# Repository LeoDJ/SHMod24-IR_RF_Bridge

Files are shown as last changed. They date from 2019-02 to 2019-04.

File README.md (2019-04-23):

# SHMod24 Addon: RF/IR Bridge

This addon is meant to be plugged onto a [SHMod24](https://github.com/LeoDJ/SHMod24) base board.
It provides the ability to send and receive infrared and 433MHz RF remote control codes.

**Current status**: a prototype PCB batch has been ordered and will be tested for functionality

## 3D Preview

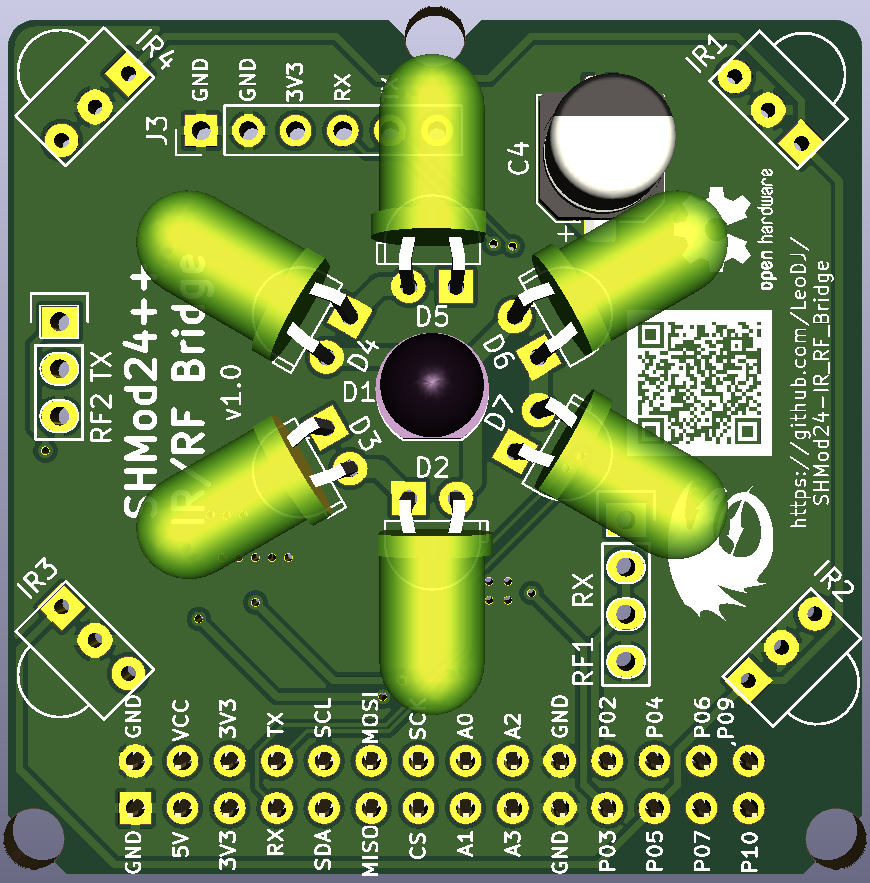
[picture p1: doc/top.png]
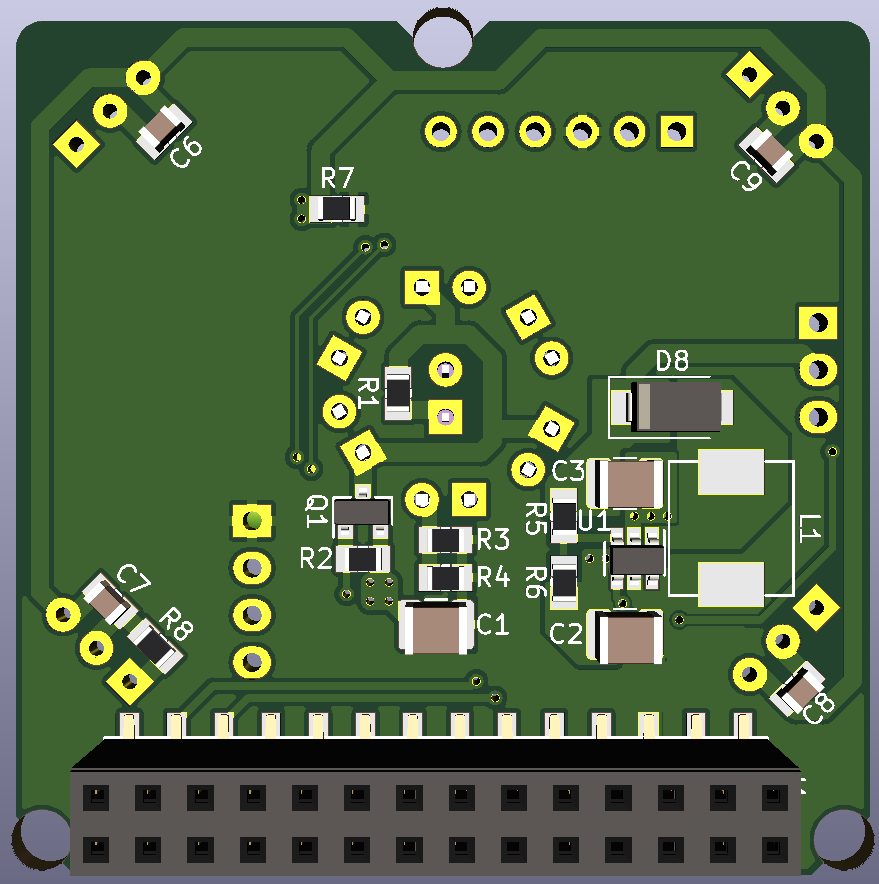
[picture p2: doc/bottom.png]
|  |  |
| :--- | :--- |
| []() | []() |

## BOM
There are multiple different module groups that can be populated.

 In the table is listed, which components to populate for a given module:

| Module | Reference | Part |
| :--- | :--- | :--- |
| **IR LED Array** | Q1 | AO3400A |
| | R1 | 15Ω |
| | R2 | 10k |
| | R3, R4 | 2Ω |
| | C1 | 22µF, 1210 |
| | D1 - D7 | IR LED 5mm |
| | | |
| **IR Receiver Array** | R7 | 100Ω |
| | C4 | 100µF, 6.3x5.8 |
| | R8 | 47k |
| | C6 - C9 | 100n |
| | IR1 - IR4 | VS1838b |
| | | |
| **433MHz 12V Boost Converter** | U1 | MT3608 |
| Can also be bypassed by | R5 | 180k |
| bridging L1 and D8 to run | R6 | 10k |
| 433MHz transmitter at 3.3V | D8 | SS34 Schottky, SMA |
| | C2, C3 | 22µF, 1210 |
| | L1 | 4.7µH, 0630 |
| | | |
| **433MHz Receiver** | RF1 | Generic China 433MHz RX |
| | | |
| **433MHz Transmitter** | RF2 | Generic China 433MHz TX |

## Project installation
- Make sure to run `git clone` with `--recurse-submodules` to include the necessary libraries too.

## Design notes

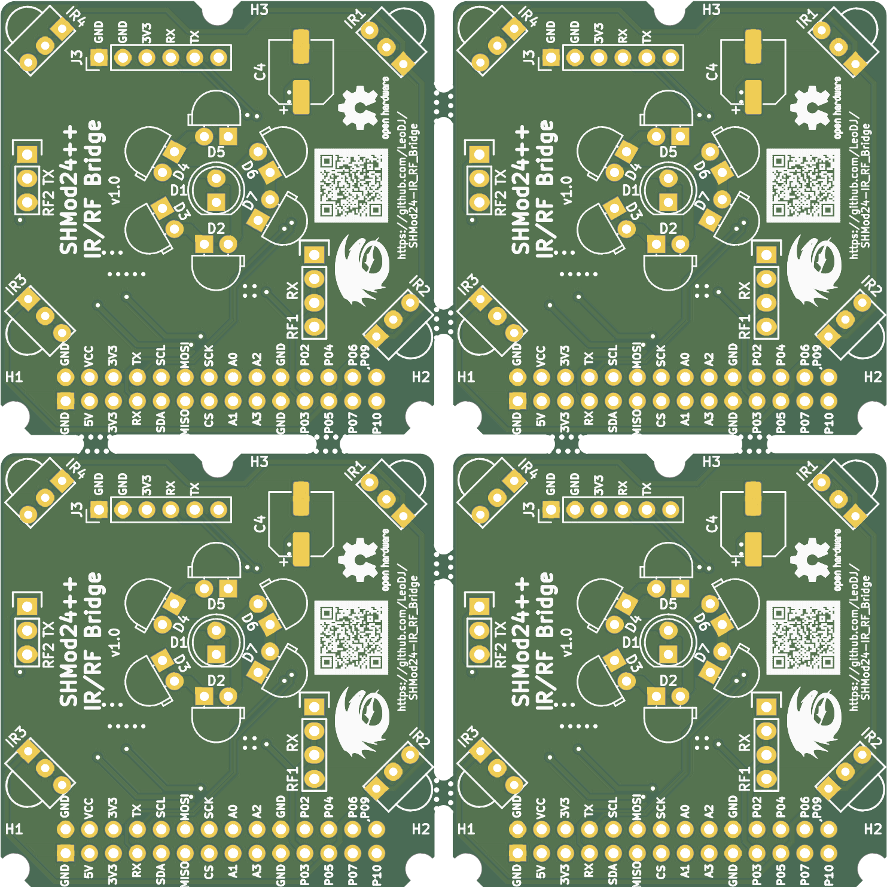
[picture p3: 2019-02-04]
gerber/panelized/panelized_Combined_Top.png

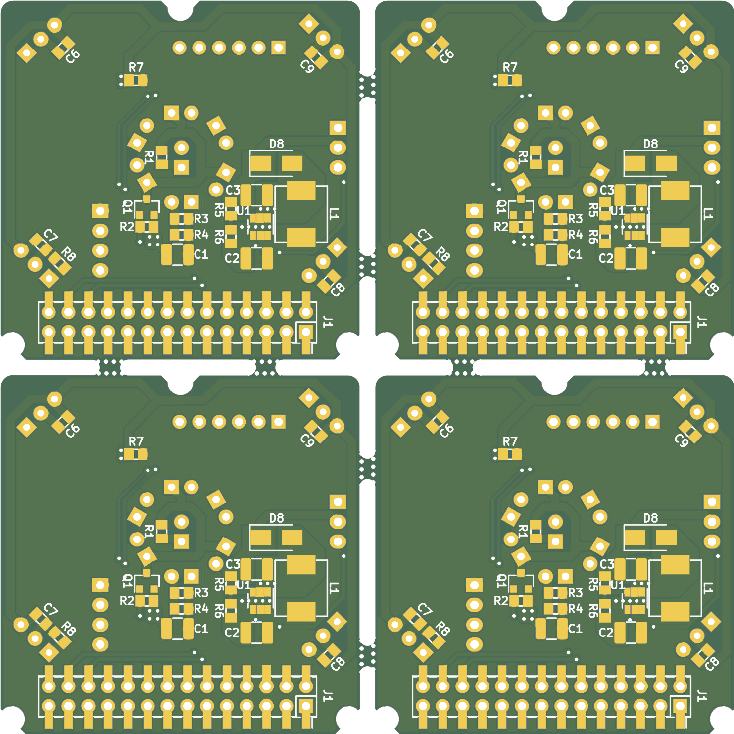
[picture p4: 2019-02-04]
gerber/panelized/panelized_Combined_Bottom.png

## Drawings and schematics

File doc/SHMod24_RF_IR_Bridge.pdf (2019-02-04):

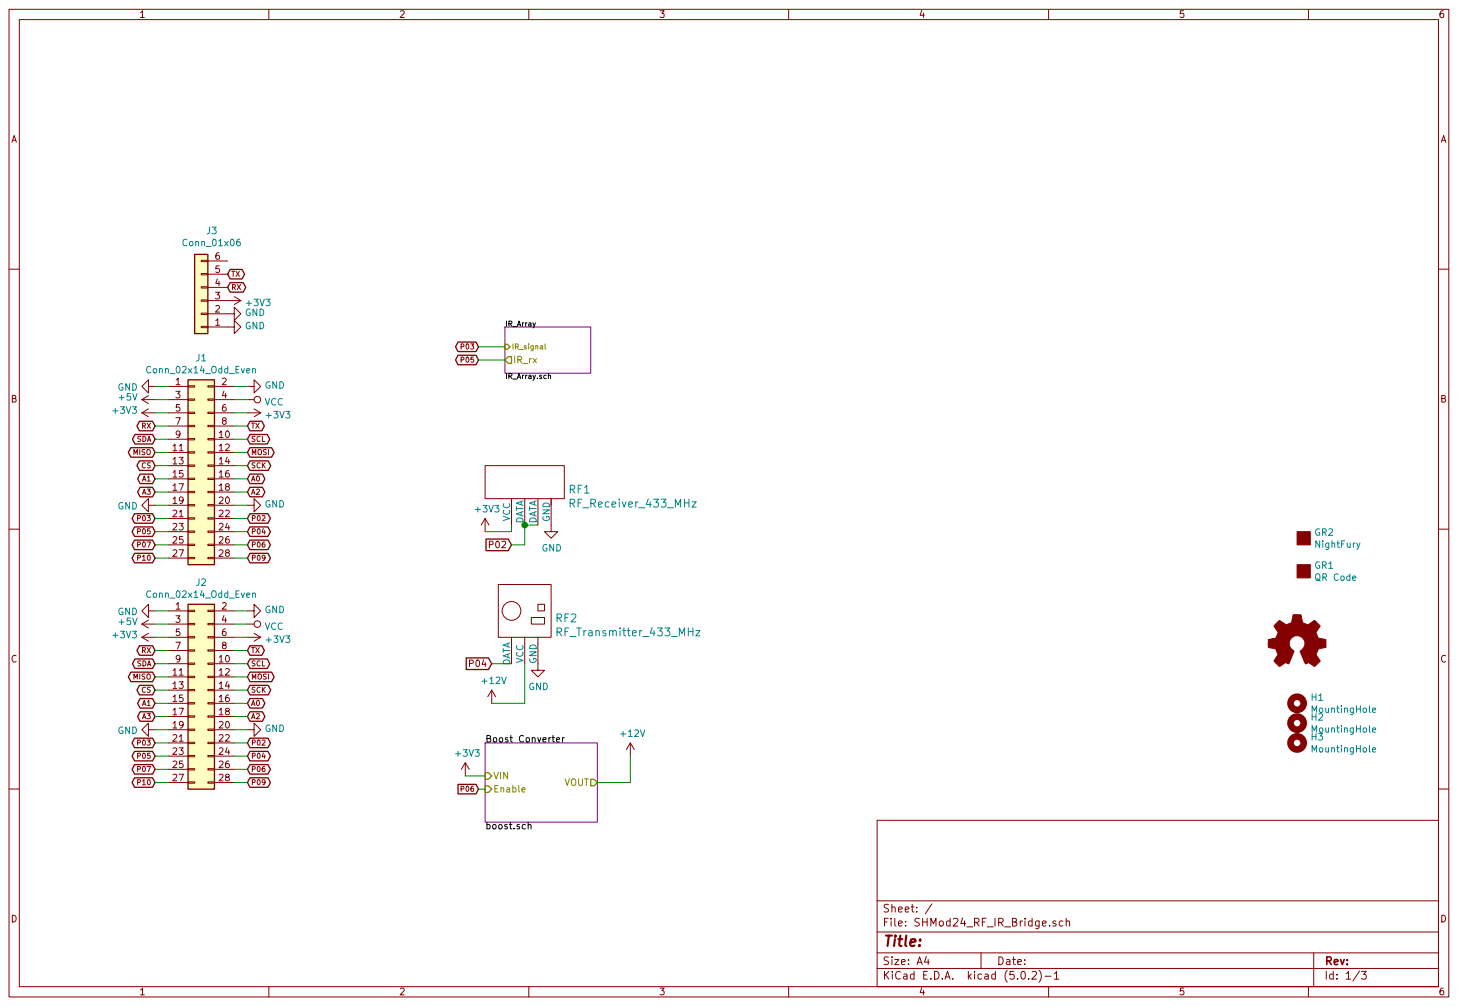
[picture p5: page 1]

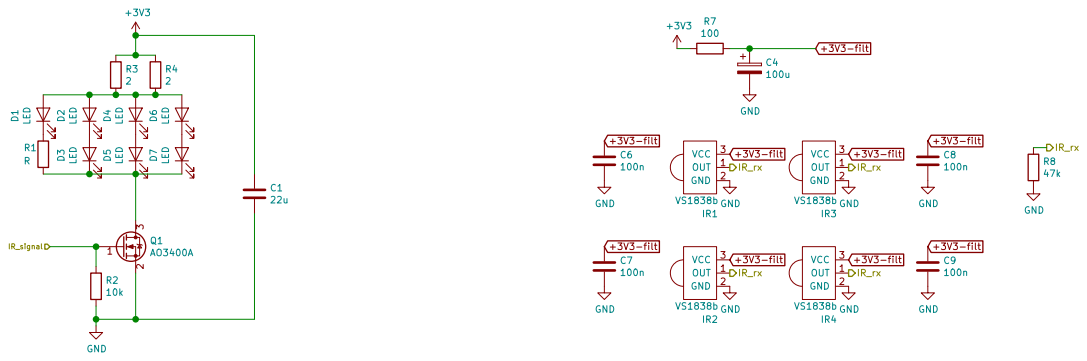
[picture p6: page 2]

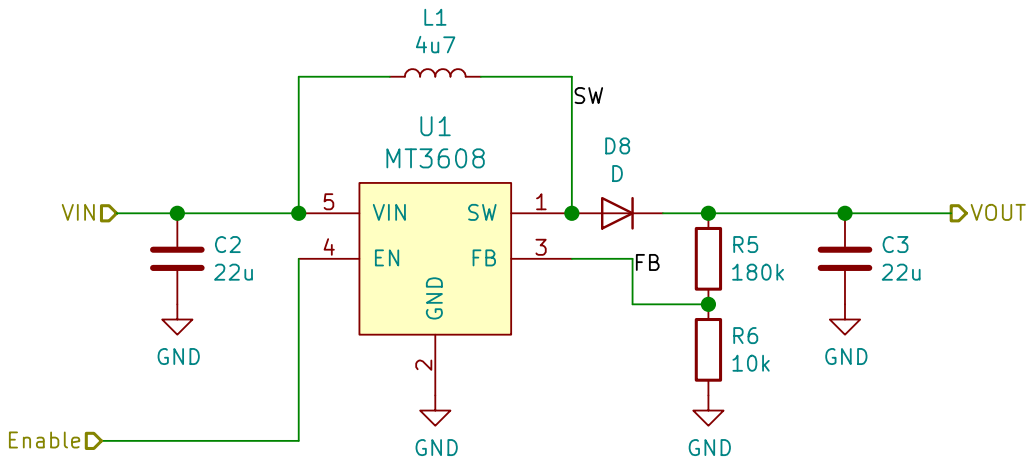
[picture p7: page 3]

2 FB 3 EN 4 VIN 5 U1 MT3608 GND

Id: 3/3 Title: File: boost.sch Sheet: /Boost Converter/

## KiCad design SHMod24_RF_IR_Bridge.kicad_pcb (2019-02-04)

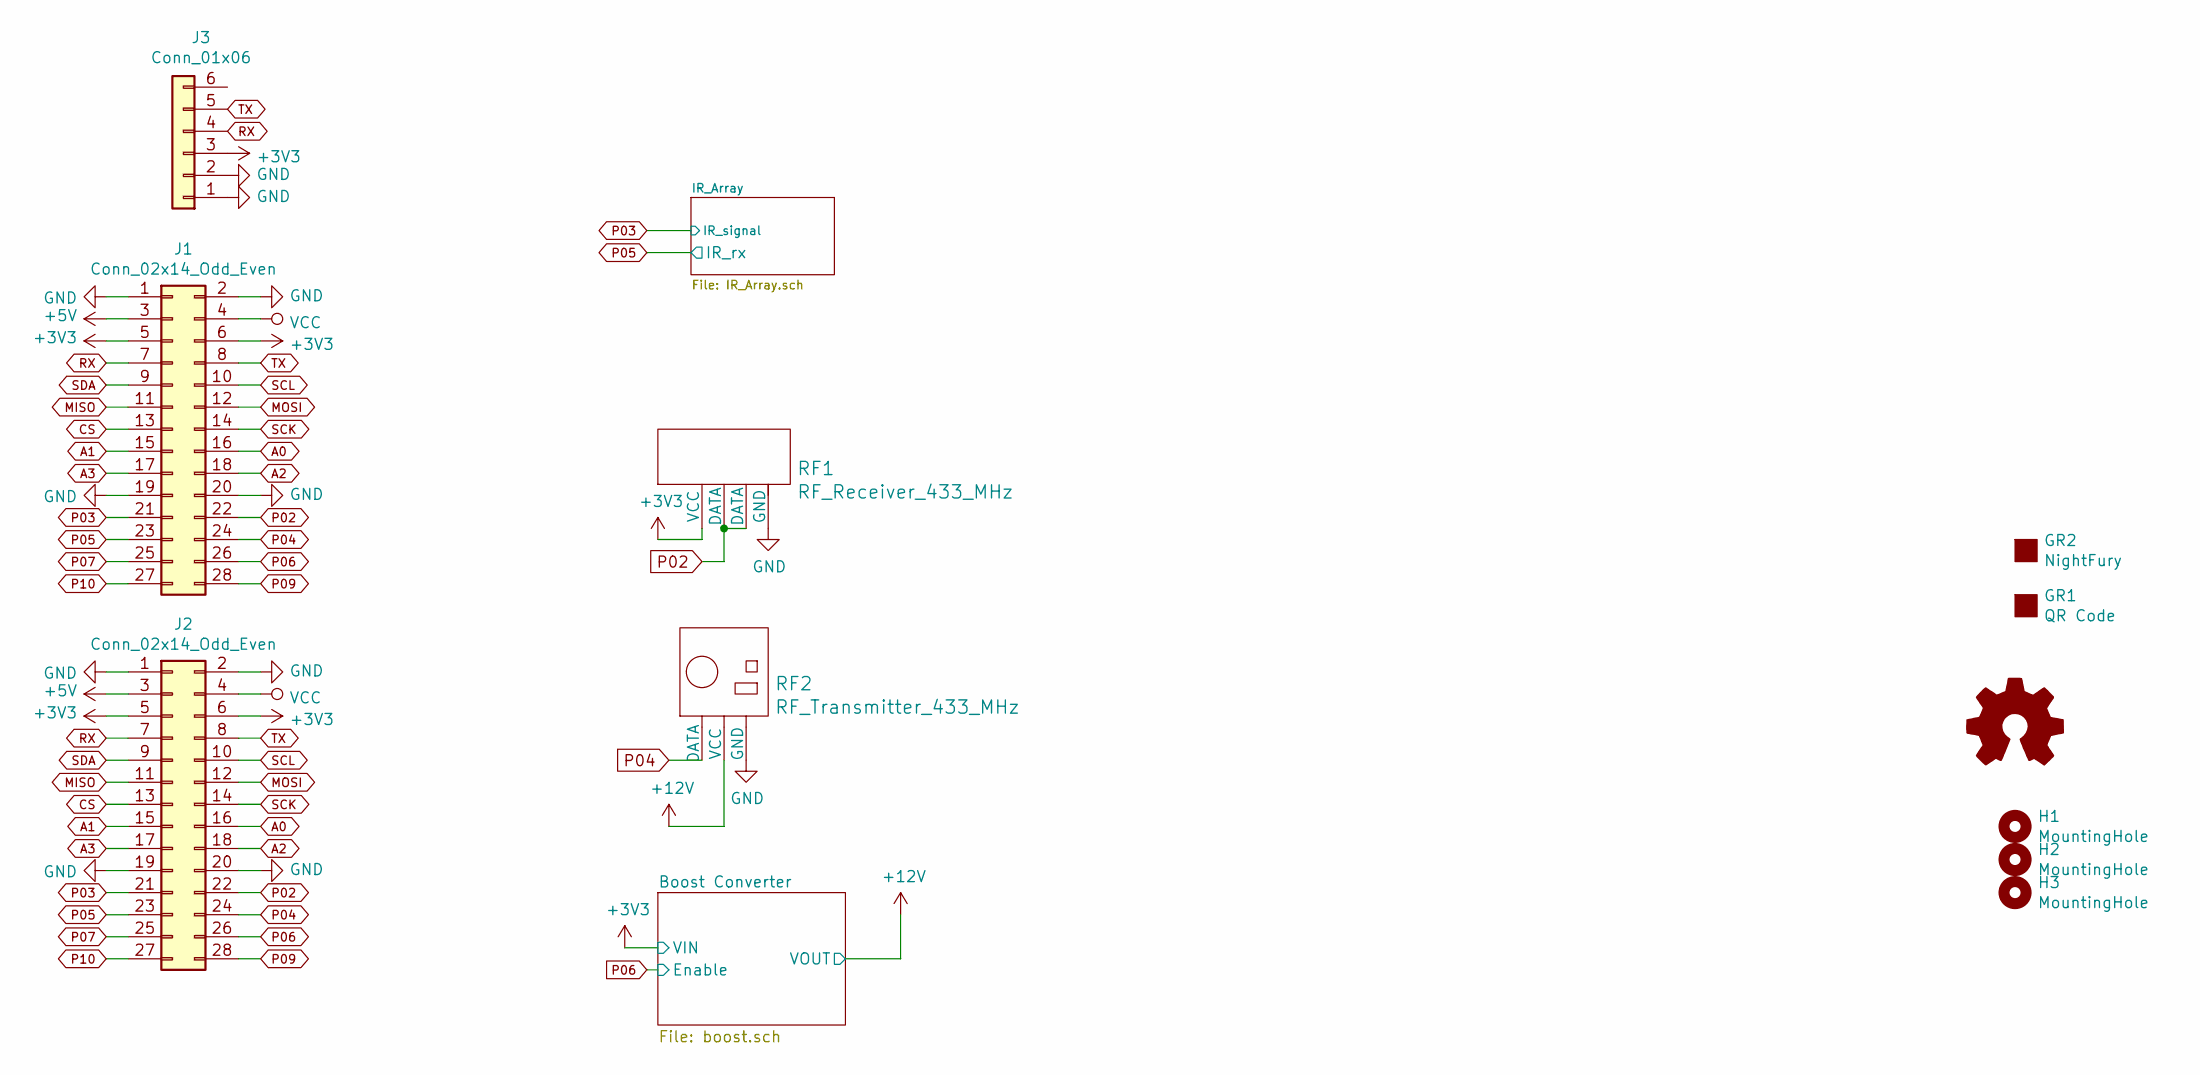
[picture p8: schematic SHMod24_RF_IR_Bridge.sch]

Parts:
GR1: QR Code; QR_Code_SHMod24-IRRF
GR2: NightFury; NightFury_Roll_8.0x6.1
H1, H2, H3: MountingHole; MountingHole_3.2mm_M3
J1: Conn_02x14_Odd_Even; PinSocket_2x14_P2.54mm_Vertical
J2: Conn_02x14_Odd_Even; PinSocket_2x14_P2.54mm_Vertical_SMD
J3: Conn_01x06; PinHeader_1x06_P2.54mm_Vertical
LOGO1: Logo_Open_Hardware_Small; OSHW-Logo2_7.3x6mm_SilkScreen
RF1: RF_Receiver_433_MHz
RF2: RF_Transmitter_433_MHz

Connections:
+3V3: J1.5, J1.6, J2.5, J2.6, J3.3, RF1.1 (VCC); also elsewhere on the board
+5V: J1.3, J2.3
+12V: RF2.2 (VCC); also elsewhere on the board
A0: J1.16, J2.16
A1: J1.15, J2.15
A2: J1.18, J2.18
A3: J1.17, J2.17
CS: J1.13, J2.13
GND: J1.1, J1.2, J1.19, J1.20, J2.1, J2.2, J2.19, J2.20, J3.1, J3.2, RF1.4 (GND), RF2.3 (GND); also elsewhere on the board
MISO: J1.11, J2.11
MOSI: J1.12, J2.12
P02: J1.22, J2.22, RF1.2 (DATA), RF1.3 (DATA)
P03: J1.21, J2.21; also elsewhere on the board
P04: J1.24, J2.24, RF2.1 (DATA)
P05: J1.23, J2.23; also elsewhere on the board
P06: J1.26, J2.26; also elsewhere on the board
P07: J1.25, J2.25
P09: J1.28, J2.28
P10: J1.27, J2.27
RX: J1.7, J2.7, J3.4
SCK: J1.14, J2.14
SCL: J1.10, J2.10
SDA: J1.9, J2.9
TX: J1.8, J2.8, J3.5
VCC: J1.4, J2.4

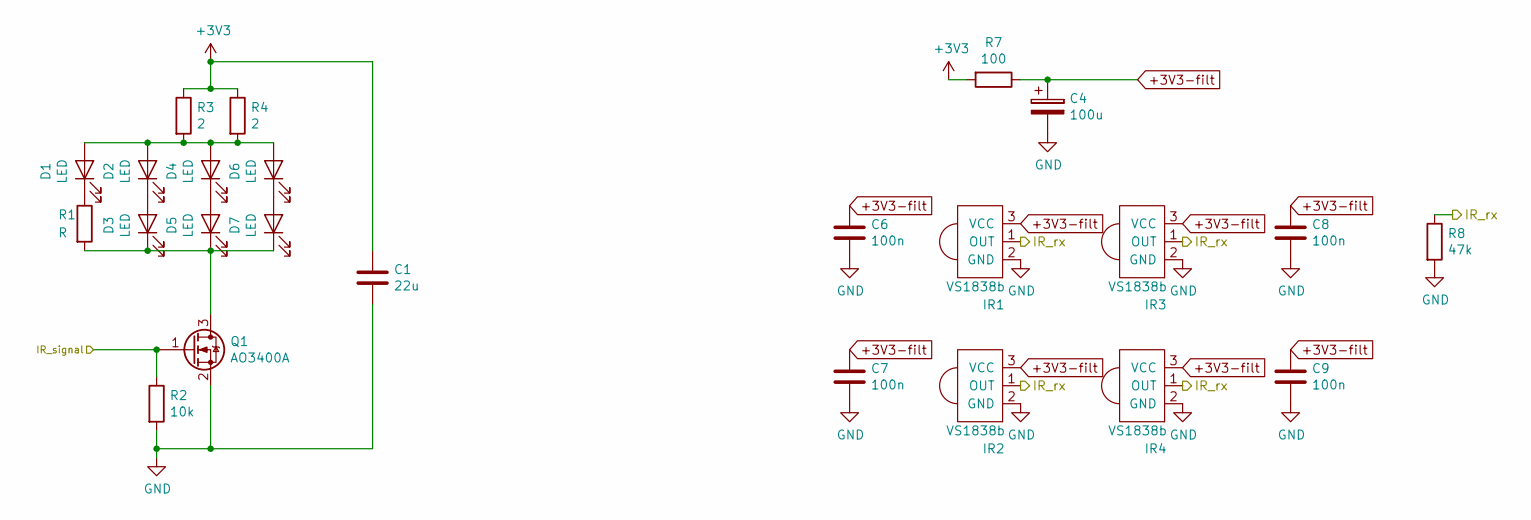
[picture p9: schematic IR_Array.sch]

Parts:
C1: 22u; C_1210_3225Metric
C4: 100u; CP_Elec_6.3x5.8
C6, C7, C8, C9: 100n; C_0805_2012Metric
D1: LED; LED_D5.0mm_IRBlack
D2, D3, D4, D5, D6, D7: LED; LED_D5.0mm_Horizontal_O1.27mm_Z9.0mm
IR1, IR2, IR3, IR4: VS1838b
Q1: AO3400A; SOT-23
R1: R; R_0805_2012Metric
R2: 10k; R_0805_2012Metric
R3, R4: 2; R_0805_2012Metric
R7: 100; R_0805_2012Metric
R8: 47k; R_0805_2012Metric

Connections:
+3V3: C1.1, R3.1, R4.1, R7.2; also elsewhere on the board
+3V3-filt: C4.1, C6.1, C7.1, C8.1, C9.1, IR1.3 (VCC), IR2.3 (VCC), IR3.3 (VCC), IR4.3 (VCC), R7.1
GND: C1.2, C4.2, C6.2, C7.2, C8.2, C9.2, IR1.2 (GND), IR2.2 (GND), IR3.2 (GND), IR4.2 (GND), Q1.2 (S), R2.2, R8.2; also elsewhere on the board
unnamed: D1.1 (K), R1.1
unnamed: D1.2 (A), D2.2 (A), D4.2 (A), D6.2 (A), R3.2, R4.2
unnamed: D2.1 (K), D3.2 (A)
unnamed: D3.1 (K), D5.1 (K), D7.1 (K), Q1.3 (D), R1.2
unnamed: D4.1 (K), D5.2 (A)
unnamed: D6.1 (K), D7.2 (A)
P03: Q1.1 (G), R2.1; also elsewhere on the board
P05: IR1.1 (OUT), IR2.1 (OUT), IR3.1 (OUT), IR4.1 (OUT), R8.1; also elsewhere on the board

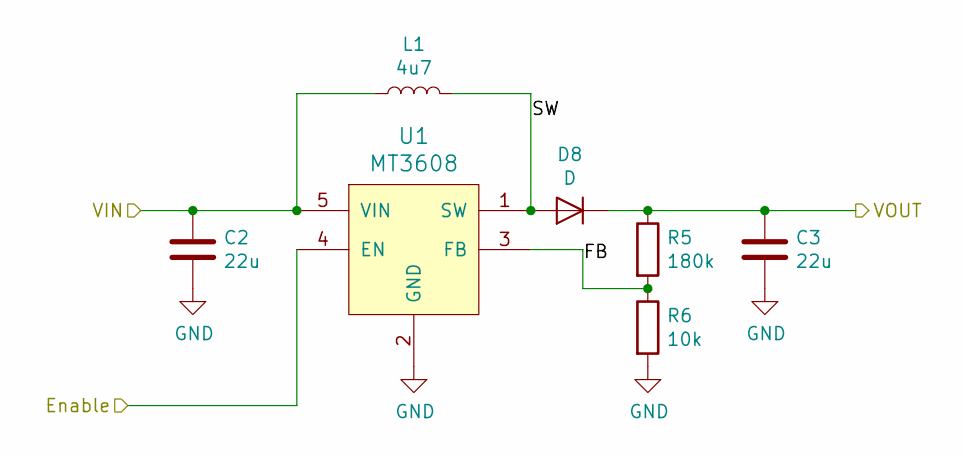
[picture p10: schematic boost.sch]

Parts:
C2, C3: 22u; C_1210_3225Metric
D8: D; D_SMA
L1: 4u7; L_0630
R5: 180k; R_0805_2012Metric
R6: 10k; R_0805_2012Metric
U1: MT3608; SOT-23-6

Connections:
+3V3: C2.1, L1.1, U1.5 (VIN); also elsewhere on the board
+12V: C3.1, D8.1 (K), R5.1; also elsewhere on the board
/Boost Converter/FB: R5.2, R6.1, U1.3 (FB)
/Boost Converter/SW: D8.2 (A), L1.2, U1.1 (SW)
GND: C2.2, C3.2, R6.2, U1.2 (GND); also elsewhere on the board
P06: U1.4 (EN); also elsewhere on the board

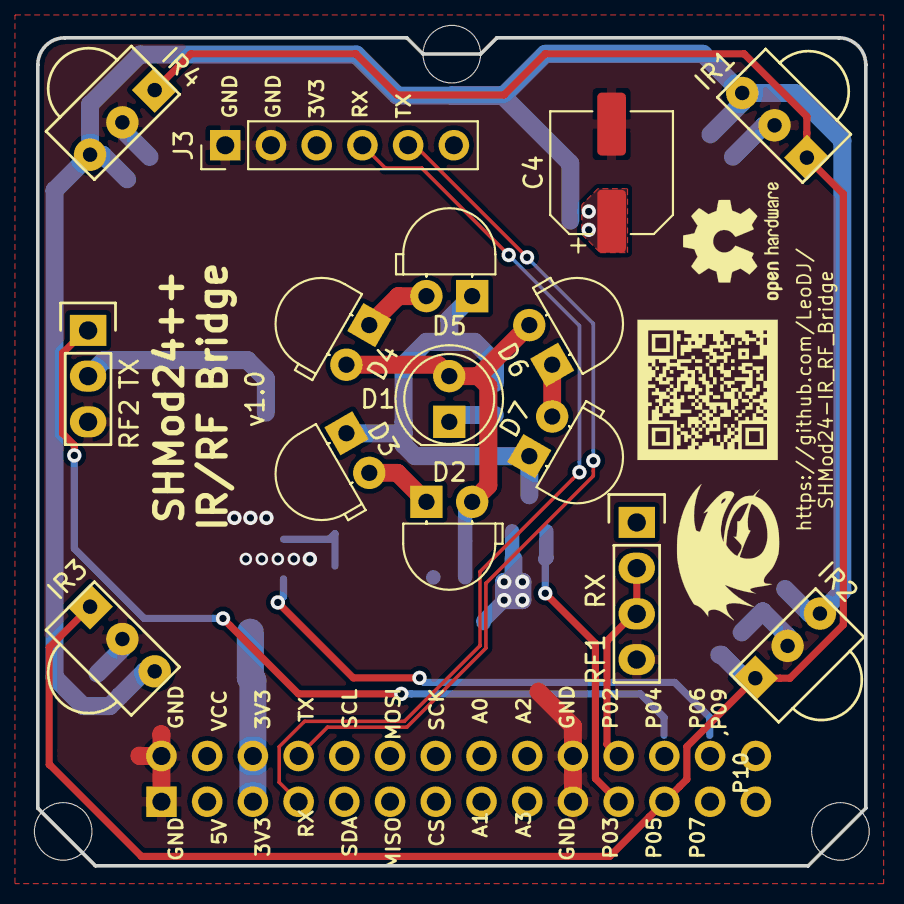
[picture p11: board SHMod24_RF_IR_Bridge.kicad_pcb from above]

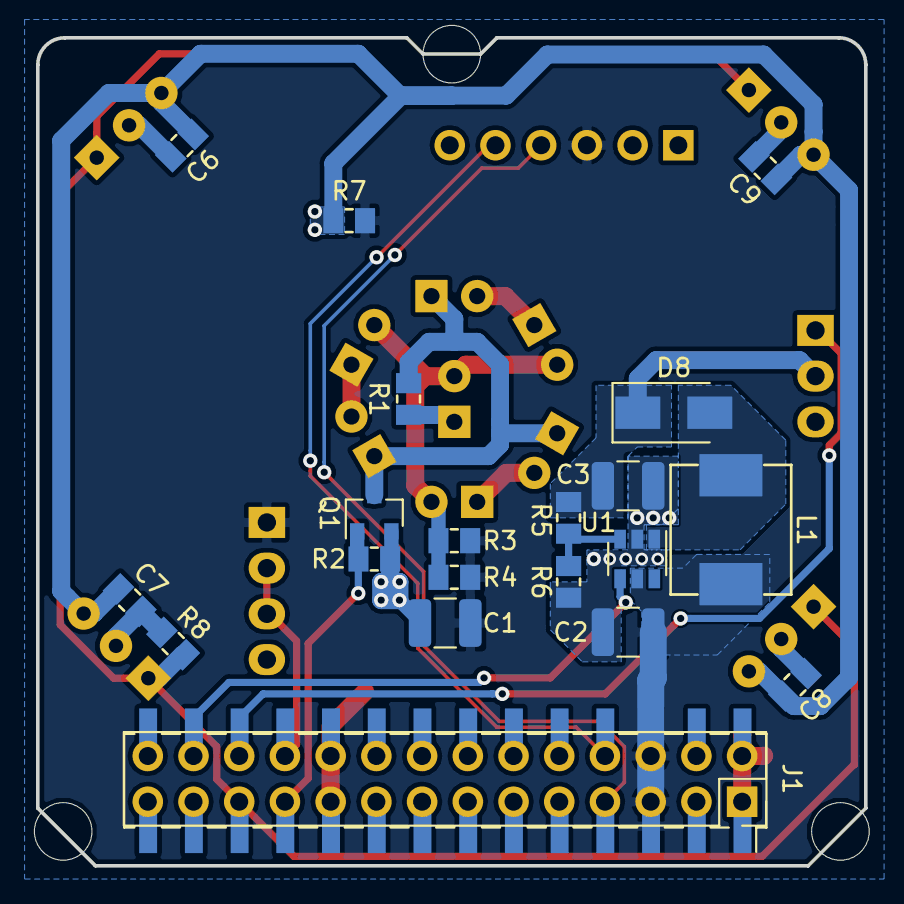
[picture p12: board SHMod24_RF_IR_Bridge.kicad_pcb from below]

Board: 2 copper layers, 46.0 x 46.0 mm, 42 parts (21 on the bottom side), 34 nets.

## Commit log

2019-01-15 initial commit
    basic SHMod24 addon board layout with holes and header done
    [SHMod24_RF_IR_Bridge.kicad_pcb, SHMod24_RF_IR_Bridge.sch]
2019-01-16 add smd pin header option
    [SHMod24_RF_IR_Bridge.kicad_pcb, SHMod24_RF_IR_Bridge.sch]
2019-01-17 design IR send / receive
    [IR_Array.sch, SHMod24_RF_IR_Bridge.kicad_pcb, SHMod24_RF_IR_Bridge.sch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]
2019-01-30 add boost converter, IR RX, 433MHz RX/TX and labels
    [IR_Array.sch, SHMod24_RF_IR_Bridge.kicad_pcb, SHMod24_RF_IR_Bridge.sch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]
2019-01-30 add serial comms header
    [IR_Array.sch, SHMod24_RF_IR_Bridge.kicad_pcb, SHMod24_RF_IR_Bridge.sch]
2019-02-04 final touches
    [SHMod24_RF_IR_Bridge.kicad_pcb, SHMod24_RF_IR_Bridge.sch]
2019-02-04 generate gerbers
    [SHMod24_RF_IR_Bridge-B.Cu.gbl, SHMod24_RF_IR_Bridge-B.Mask.gbs, SHMod24_RF_IR_Bridge-B.SilkS.gbo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]
2019-04-23 add BOM
